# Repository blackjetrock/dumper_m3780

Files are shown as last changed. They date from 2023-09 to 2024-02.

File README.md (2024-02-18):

# dumper_m3780
Dumper for the M3780 microcontroller family
===========================================

Uses Sean Riddle's dumper circuit, but with a RP Pico instead of the
PIC. I ported Sean's code over to the Pico but couldn't get reliable
reads, so I rewrote it to use a generic system of injecting instructions
and used a more elaborate scheme to get the data out of the device. This 
is very much a hacked together tool specifically built to dump a ROM. It's not
a finished product.

The TEST pin handling is the same as Sean's code, but I have code that
can inject a (preset, in arrays) sequence of code into the device. This
allowed me to debug my instruction extraction and come up with a method of 
reading ROM bytes reliably. As I still had issues with a value every
few hundred bytes I now read each byte in the ROM many times and only if
that block read gives the same value is it used as the ROM byte value.
If the values aren't the same then the block of reads is re-done 
until it is. This means it takes a while to read the ROM but the 
values are, I think, correct. I checked operation with the Boris chess
computer ROM and I got a dump that matched Sean's ecxept for the last
few bytes which are, I think, unused values.

I then dumped the ROM from a device out of an HP82143 printer. The Boris 
and HP dumps are in this repository.

The PCB is powered by the Pico USB, whih also has a menu system to drive the
code and get dumps.

At the moment the code always dumps 4K

ERRATA
======

V1.0 PCB
--------

This version of the PCB does not work unless you add level shifters 
between the Pico and the 4066 control lines. I added a couple of FETs
onto my PCB manually. If you don't do this then the PCB will
not work.

Here's the V1.0 PCB I used:

IMAG4222

You can see a dc-dc converter module on the right, and the level shifters I wired in going from the 4066 
to the Pico on the left. The 40 pin IC is the M3780. the two LM317T circuits are on the right with their 
adjustment potentiometers.

Code
----
There's a menu system on the USB. Press 'h' to see the command list. To dump a ROM use 'u' then 'S' to dump the ROM. It takes a while as each byte
is read, when it's done the full dumpo is displayed. There's some problem that means that you need to select 'u'
before using 'S'. As this is a one or two use dumper, I'm not bothered by these wrinkles.

Links
=====

<pre>
Sean Riddle's site:                     https://seanriddle.com/
Forum thread:                           https://www.hpmuseum.org/forum/thread-20043.html
</pre>

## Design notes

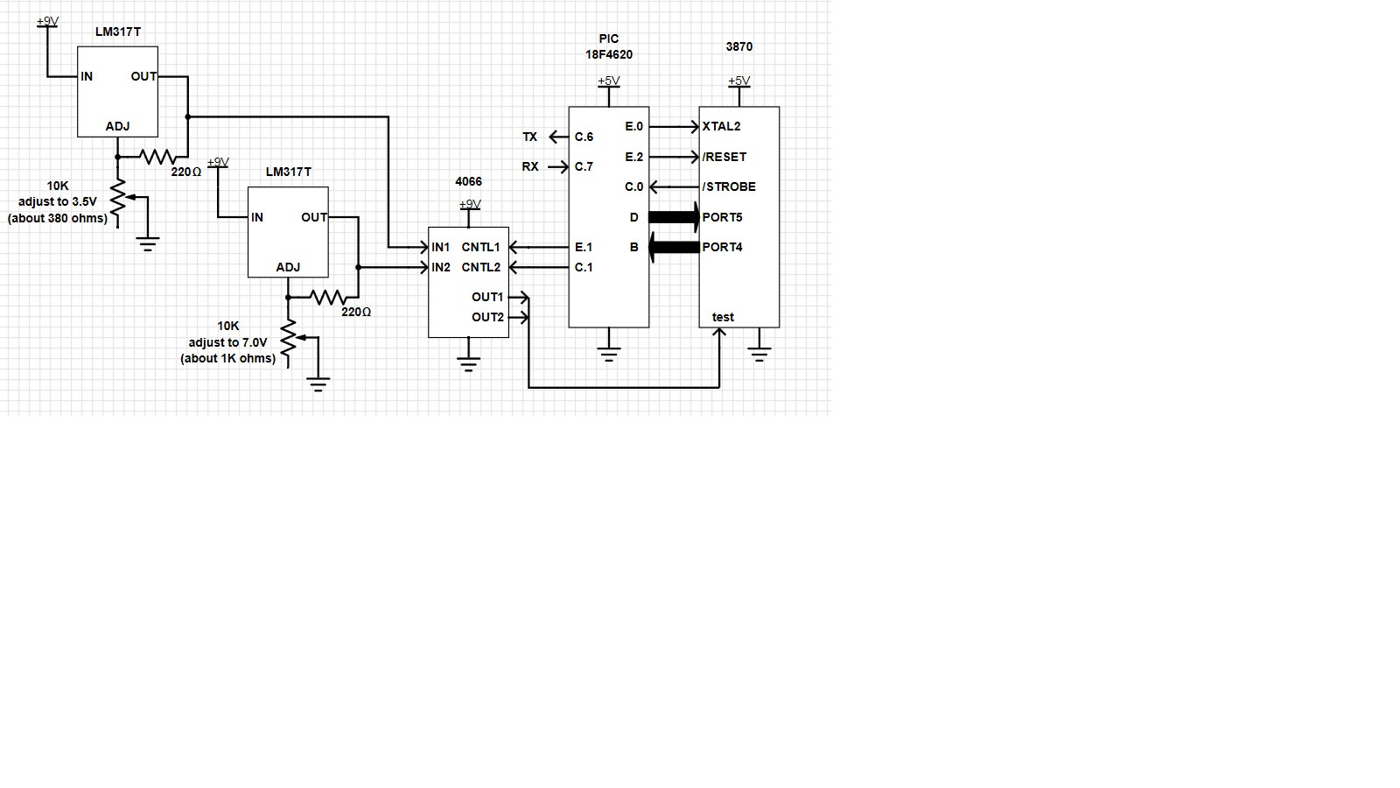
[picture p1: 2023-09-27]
sean_riddle/3870dumper.jpg

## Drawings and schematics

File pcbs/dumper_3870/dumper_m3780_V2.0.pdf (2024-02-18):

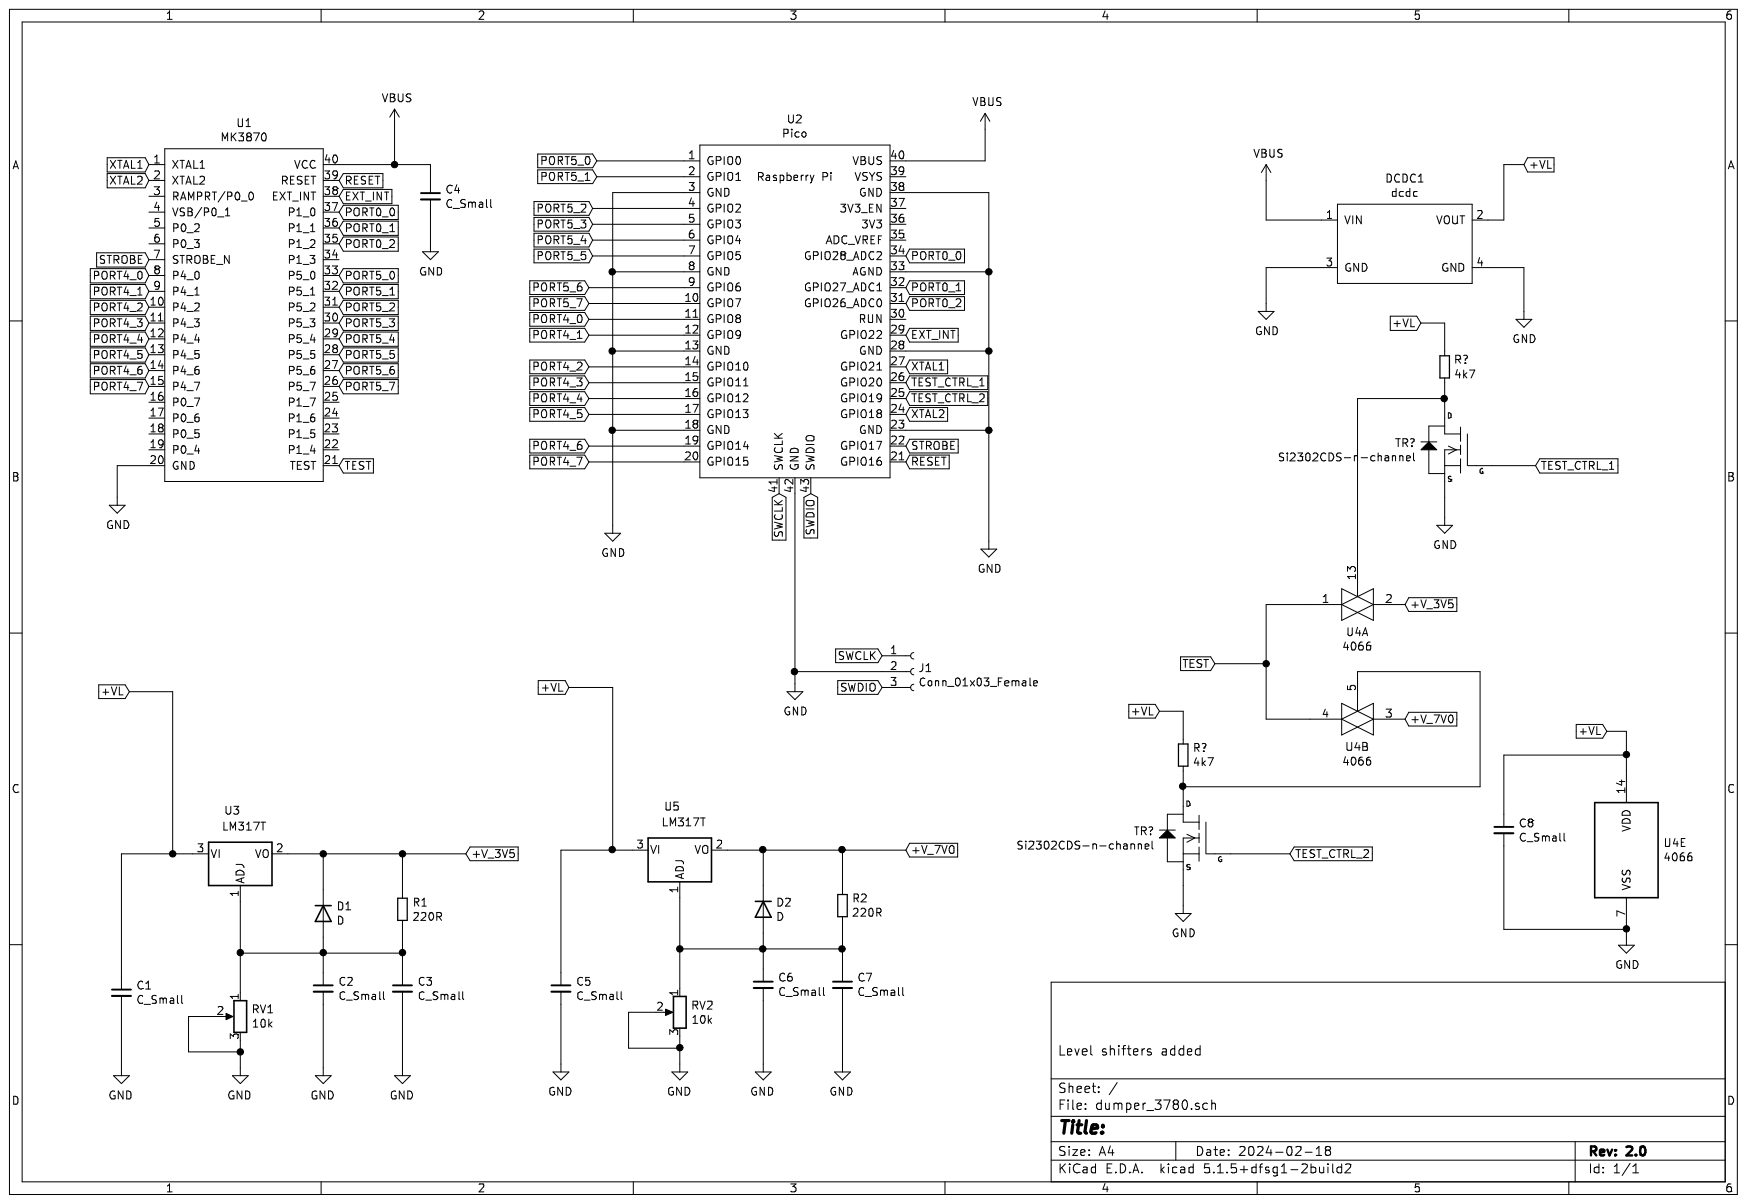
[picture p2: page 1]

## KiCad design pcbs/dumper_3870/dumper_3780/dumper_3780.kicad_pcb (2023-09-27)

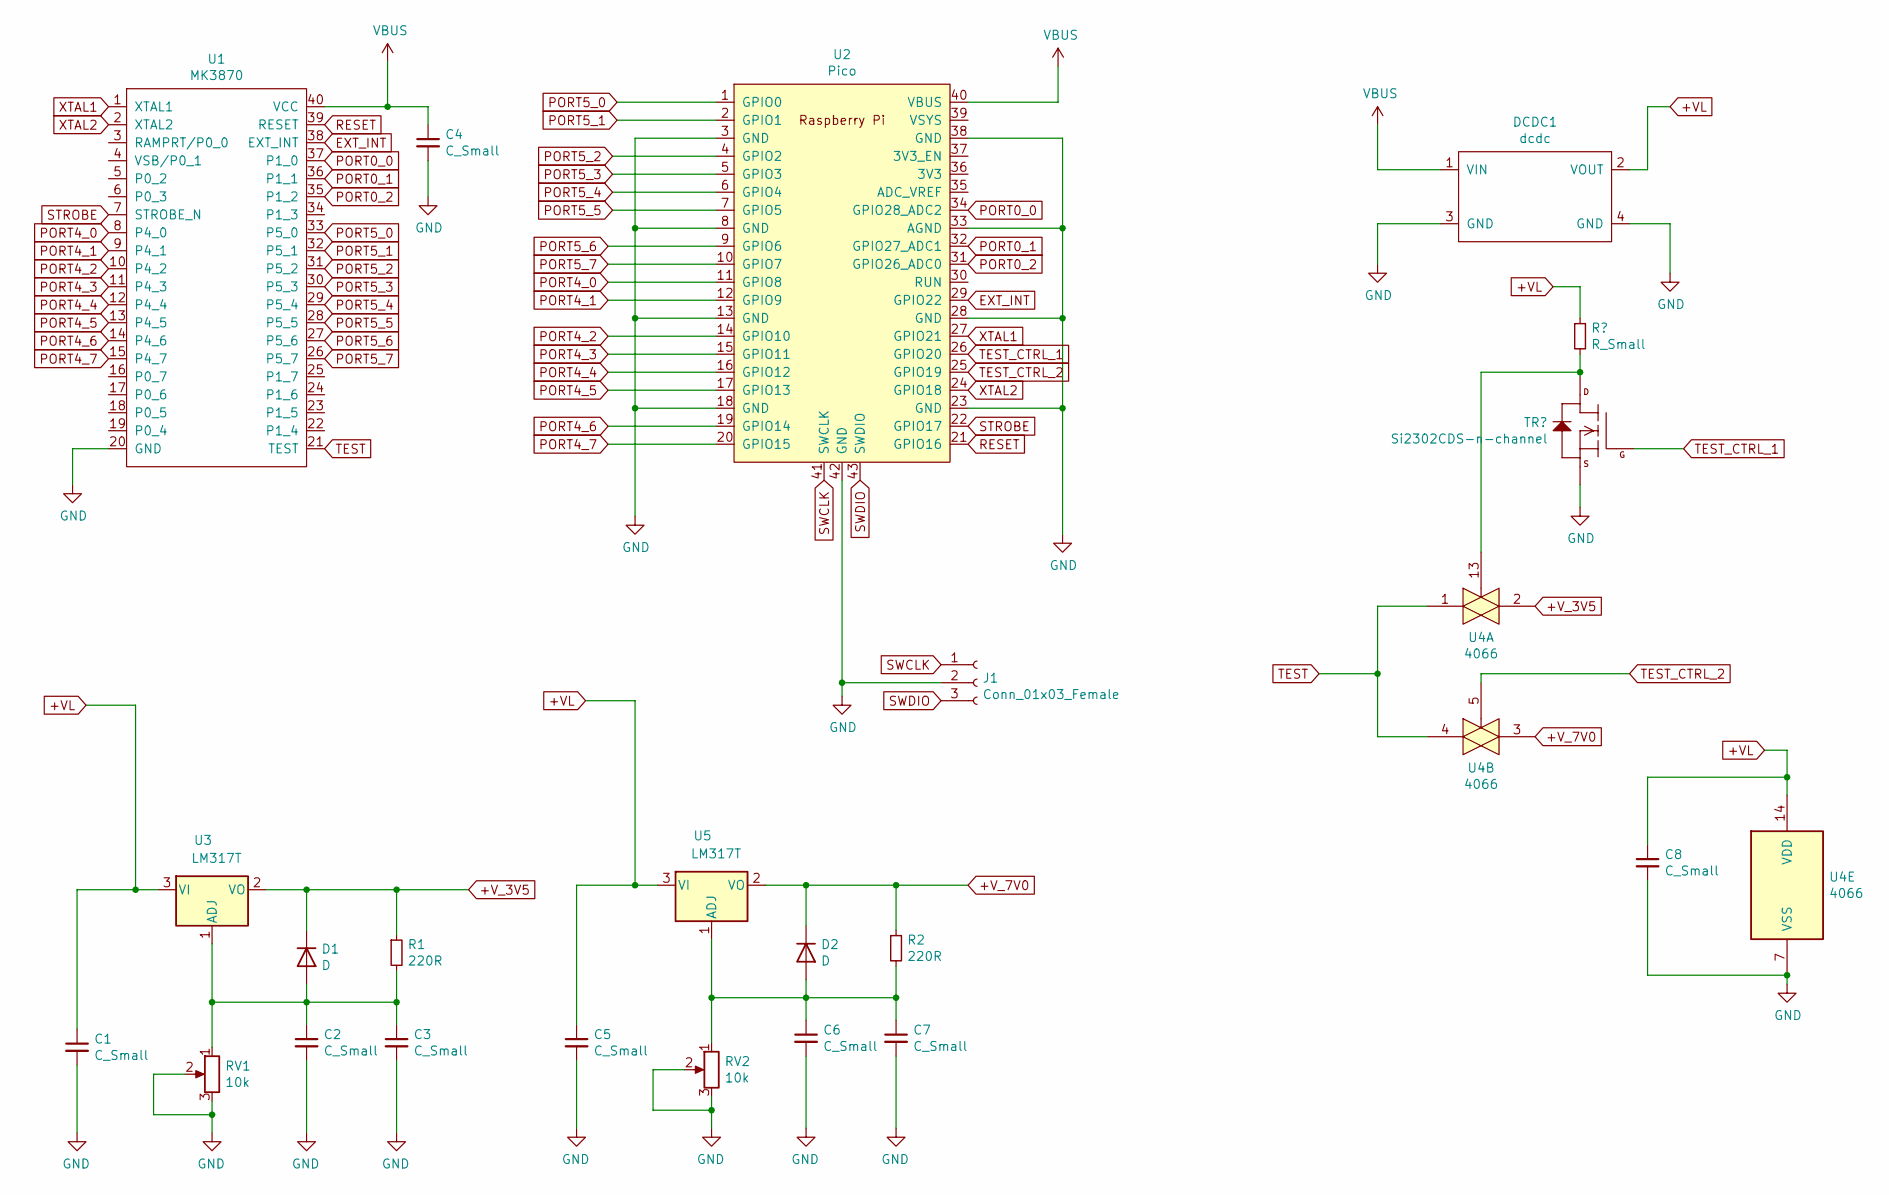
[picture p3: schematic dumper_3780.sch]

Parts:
C1, C2, C3, C4, C5, C6, C7, C8: C_Small; C_0805_2012Metric_Pad1.18x1.45mm_HandSolder
D1, D2: D; D_SOD-123
DCDC1: dcdc; PinSocket_1x04_P2.54mm_Vertical
J1: Conn_01x03_Female; PinSocket_1x03_P2.54mm_Vertical
R1, R2: 220R; R_0805_2012Metric_Pad1.20x1.40mm_HandSolder
RV1, RV2: 10k; Potentiometer_Bourns_3299W_Vertical
U1: MK3870; DIP-40_W15.24mm
U2: Pico; RPi_Pico_SMD_TH
U3, U5: LM317T; TO-220-3_Vertical
U4: 4066; SOIC-14_3.9x8.7mm_P1.27mm

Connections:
+VL: C1.1, C5.1, C8.1, DCDC1.2 (VOUT), U3.3 (VI), U4.14 (VDD), U5.3 (VI)
+V_3V5: D1.1 (K), R1.1, U3.2 (VO), U4.2
+V_7V0: D2.1 (K), R2.1, U4.3, U5.2 (VO)
EXT_INT: U1.38 (EXT_INT), U2.29 (GPIO22)
GND: C1.2, C2.2, C3.2, C4.2, C5.2, C6.2, C7.2, C8.2, DCDC1.3 (GND), DCDC1.4 (GND), J1.2, RV1.2, RV1.3, RV2.2, RV2.3, U1.20 (GND), U2.3 (GND), U2.8 (GND), U2.13 (GND), U2.18 (GND), U2.23 (GND), U2.28 (GND), U2.33 (AGND), U2.38 (GND), U2.42 (GND), U4.7 (VSS)
unnamed: C2.1, C3.1, D1.2 (A), R1.2, RV1.1, U3.1 (ADJ)
unnamed: C6.1, C7.1, D2.2 (A), R2.2, RV2.1, U5.1 (ADJ)
PORT0_0: U1.37 (P1_0), U2.34 (GPIO28_ADC2)
PORT0_1: U1.36 (P1_1), U2.32 (GPIO27_ADC1)
PORT0_2: U1.35 (P1_2), U2.31 (GPIO26_ADC0)
PORT4_0: U1.8 (P4_0), U2.11 (GPIO8)
PORT4_1: U1.9 (P4_1), U2.12 (GPIO9)
PORT4_2: U1.10 (P4_2), U2.14 (GPIO10)
PORT4_3: U1.11 (P4_3), U2.15 (GPIO11)
PORT4_4: U1.12 (P4_4), U2.16 (GPIO12)
PORT4_5: U1.13 (P4_5), U2.17 (GPIO13)
PORT4_6: U1.14 (P4_6), U2.19 (GPIO14)
PORT4_7: U1.15 (P4_7), U2.20 (GPIO15)
PORT5_0: U1.33 (P5_0), U2.1 (GPIO0)
PORT5_1: U1.32 (P5_1), U2.2 (GPIO1)
PORT5_2: U1.31 (P5_2), U2.4 (GPIO2)
PORT5_3: U1.30 (P5_3), U2.5 (GPIO3)
PORT5_4: U1.29 (P5_4), U2.6 (GPIO4)
PORT5_5: U1.28 (P5_5), U2.7 (GPIO5)
PORT5_6: U1.27 (P5_6), U2.9 (GPIO6)
PORT5_7: U1.26 (P5_7), U2.10 (GPIO7)
RESET: U1.39 (RESET), U2.21 (GPIO16)
STROBE: U1.7 (STROBE_N), U2.22 (GPIO17)
SWCLK: J1.1, U2.41 (SWCLK)
SWDIO: J1.3, U2.43 (SWDIO)
TEST: U1.21 (TEST), U4.1, U4.4
TEST_CTRL_1: U2.26 (GPIO20), U4.13
TEST_CTRL_2: U2.25 (GPIO19), U4.5
VBUS: C4.1, DCDC1.1 (VIN), U1.40 (VCC), U2.40 (VBUS)
XTAL1: U1.1 (XTAL1), U2.27 (GPIO21)
XTAL2: U1.2 (XTAL2), U2.24 (GPIO18)

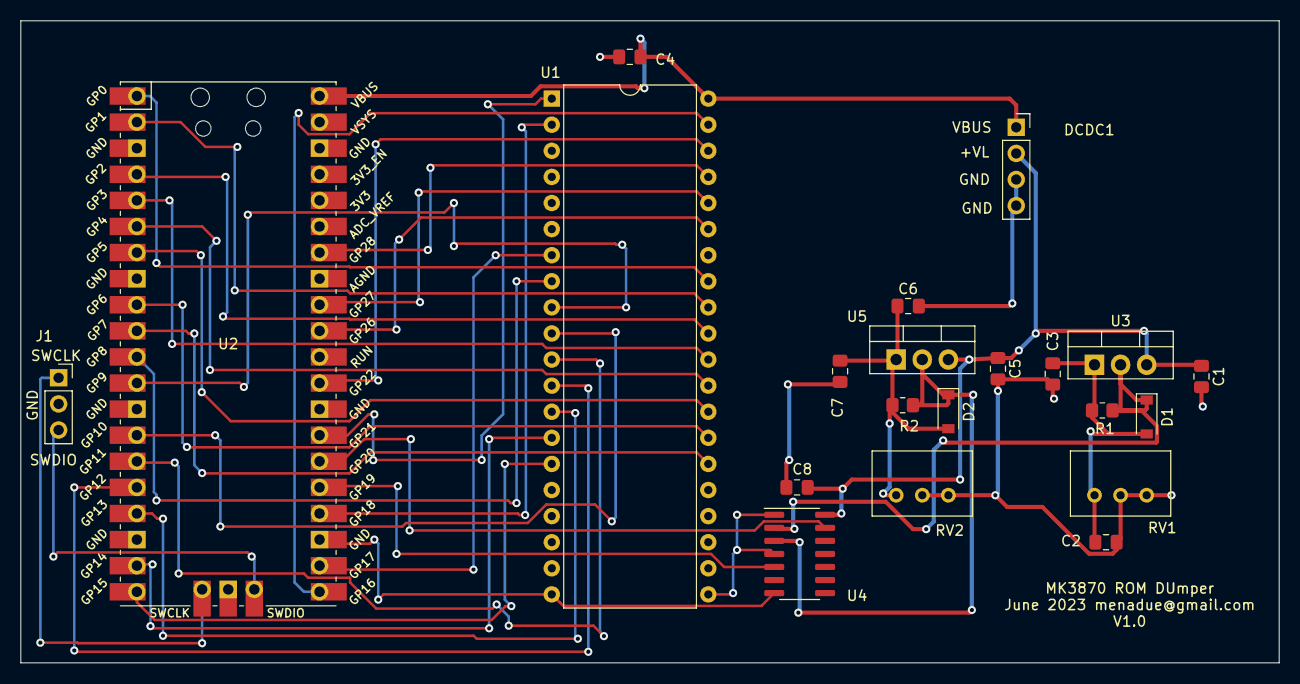
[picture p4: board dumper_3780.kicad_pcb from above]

Board: 2 copper layers, 122.5 x 62.5 mm, 21 parts (0 on the bottom side), 36 nets.

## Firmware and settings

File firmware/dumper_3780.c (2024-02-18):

////////////////////////////////////////////////////////////////////////////////
//
//  Dumper for M3780 Microcontrollers
//
////////////////////////////////////////////////////////////////////////////////
//
// Uses Sean Riddle's dumper circuit, but with a RP Pico instead of the
// PIC. I ported Sean's code over to the Pico but couldn't get reliable
// reads, so I rewrote it to use a generic system of injecting instructions
// and used a more elaborate scheme to get the data out of the device.
// 
//
////////////////////////////////////////////////////////////////////////////////

#include <ctype.h>
#include <math.h>
#include <stdio.h>
#include <stdlib.h>
#include <string.h>

#include "pico/stdlib.h"
#include "hardware/pio.h"
#include "hardware/dma.h"
#include "hardware/flash.h"
#include "hardware/structs/bus_ctrl.h"

#define DEBUG_STOP while(1) {}

// Some logic to analyse:
#include "hardware/structs/pwm.h"
#include "pico/multicore.h"
#include "pico/bootrom.h"

////////////////////////////////////////////////////////////////////////////////

#define DUMP_CODE      1
#define RAM_TEST_CODE  0

#if 0
// Gives about 2MHz clock
#define DUMP_ON_CLK   0
#define DELAY_CLK     2
#define DELAY_PORT    1
#define DELAY_VOLTS   1
#endif

int delay_clock_var = 2;

#if 1

#define DUMP_ON_CLK   0
#define DELAY_CLK     delay_clock_var
#define DELAY_PORT    1
#define DELAY_VOLTS   1
#endif

////////////////////////////////////////////////////////////////////////////////

#define CLOCK_DIV  30.0f

#define PORT_WIDTH 8

const int P_PORT5_0    = 0;
const int P_PORT5_1    = 1;
const int P_PORT5_2    = 2;
const int P_PORT5_3    = 3;
const int P_PORT5_4    = 4;
const int P_PORT5_5    = 5;
const int P_PORT5_6    = 6;
const int P_PORT5_7    = 7;

const int P_PORT4_0    = 8;
const int P_PORT4_1    = 9;
const int P_PORT4_2    = 10;
const int P_PORT4_3    = 11;
const int P_PORT4_4    = 12;
const int P_PORT4_5    = 13;
const int P_PORT4_6    = 14;
const int P_PORT4_7    = 15;

const int P_RESET      = 16;
const int P_STROBE     = 17;
const int P_XTAL2      = 18;

const int P_DRV_3V5    = 19;
const int P_DRV_7V0    = 20;
const int P_XTAL1      = 21;
const int P_EXT_INT    = 22;
const int P_PORT0_2    = 26;
const int P_PORT0_1    = 27;
const int P_PORT0_0    = 28;

typedef enum
  {
   TEST_PIN_FLOATING = 100,
   TEST_PIN_3V5,
   TEST_PIN_7V0,
  } TEST_PIN_VOLTAGE;
  

// Define some GPIO ports

const int port4[PORT_WIDTH] =
  {
   P_PORT4_0,
   P_PORT4_1,
   P_PORT4_2,
   P_PORT4_3,
   P_PORT4_4,
   P_PORT4_5,
   P_PORT4_6,
   P_PORT4_7,
  };

const int port5[PORT_WIDTH] =
  {
   P_PORT5_0,
   P_PORT5_1,
   P_PORT5_2,
   P_PORT5_3,
   P_PORT5_4,
   P_PORT5_5,
   P_PORT5_6,
   P_PORT5_7,
  };

// Opcodes (inverted)
#define DCI_OPCODE  (0x2A ^ 0xFF)
#define LM_OPCODE   (0x16 ^ 0xFF)
#define LR_OPCODE   (0x0E ^ 0xFF)
#define NOP_OPCODE  (0x2B ^ 0xFF)
#define ST_OPCODE   (0x17 ^ 0xFF)
#define LI_OPCODE   (0x20 ^ 0xFF)
#define INC_OPCODE  (0x1F ^ 0xFF)

////////////////////////////////////////////////////////////////////////////////
//
// Prototypes
//
////////////////////////////////////////////////////////////////////////////////

void serial_help(void);
void set_test_pin_voltage(TEST_PIN_VOLTAGE v);
int get_data_bus(void);
void detect_device(void);
void dump_rom(void);
void run_instructions(void);
int reset_and_detect(void);
void enable_rom(void);
void disable_rom(void);
void sweep_address(void);

volatile int perform_dump = 0;

////////////////////////////////////////////////////////////////////////////////
// Serial loop command structure
////////////////////////////////////////////////////////////////////////////////
  
typedef void (*FPTR)(void);

typedef struct
{
  char key;
  char *desc;
  FPTR fn;
} SERIAL_COMMAND;

int keypress = 0;
int parameter = 0;
int auto_increment_parameter = 0;
int auto_increment_address   = 0;

#define RAM_SIZE  (10*1024)

uint8_t ram_data[RAM_SIZE];
int dump_size = 0;

#define TEXT_PARAMETER_LEN 40

char text_parameter[TEXT_PARAMETER_LEN+1] = "";

int address = 0;

////////////////////////////////////////////////////////////////////////////////

////////////////////////////////////////////////////////////////////////////////

// Delay for less than a us
// This has to be tuned

void delay(int n)
{
  volatile int i;

  for(i=0; i<n; i++)
    {
    }
}

void set_gpio_input(int gpio_pin)
{
  gpio_init(gpio_pin);
  gpio_set_dir(gpio_pin, GPIO_IN);
  gpio_set_pulls(gpio_pin, 0, 0);

  printf("\nGPIO %d set as input", gpio_pin);
}

void set_gpio_output(int gpio_pin)
{
  gpio_init(gpio_pin);
  gpio_set_dir(gpio_pin, GPIO_OUT);
  gpio_put(gpio_pin, 0);
  printf("\nGPIO %d set as output", gpio_pin);
}

void set_port_input(const int port[PORT_WIDTH])
{
  for(int i=0; i<PORT_WIDTH; i++)
    {
      set_gpio_input(port[i]);
    }
}

void set_port_output(const int port[PORT_WIDTH])
{
  for(int i=0; i<PORT_WIDTH; i++)
    {
      set_gpio_output(port[i]);
    }
}

int read_port(const int port[PORT_WIDTH])
{
  int res = 0;

  delay(DELAY_PORT);
  
  for(int i=0; i<PORT_WIDTH; i++)
    {
      res |= (gpio_get(port[i]) << i);
    }

  return(res);
}

void write_port(const int port[PORT_WIDTH], int value)
{
  
  for(int i=0; i<PORT_WIDTH; i++)
    {
      if( value & (1<<i) )
	{
	  gpio_put(port[i], 1);
	}
      else
	{
	  gpio_put(port[i], 0);
	}
    }

  delay(DELAY_PORT);
}

void clock_low(void)
{
  gpio_put(P_XTAL2, 0);
  delay(DELAY_CLK);

#if DUMP_ON_CLK
  printf("\n   CLK LO DB:%02X", get_data_bus());
#endif
}



void clock_high(void)
{
  gpio_put(P_XTAL2, 1);

  delay(DELAY_CLK);

#if DUMP_ON_CLK
  printf("\n   CLK HI DB:%02X", get_data_bus());
#endif
}

void clock(void)
{
  clock_low();
  clock_high();
}

void double_clock(int n)
{
  for(int i=0; i<n; i++)
    {
      clock();
      clock();
    }
}


void set_data_bus(int value)
{
  write_port(port5, value);
}

int get_data_bus(void)
{
  return(read_port(port4));
}


void reset_low(void)
{
  gpio_put(P_RESET, 0);
}

void reset_high(void)
{
  gpio_put(P_RESET, 0);
}


void reset_device(void)
{
  printf("\nresetting device... ");
  reset_low();
  sleep_ms(300);
  reset_high();

  printf("  done.");
}


void display_ram_at(uint8_t *dat)
{
  int csum = 0;
  
  printf("\n");
  
  for(int z = 0; z<dump_size; z++)
    {
      int byte = 0;
      
      if( (z % 16) == 0)
	{
	  printf("\n%03X: ", z);
	}

      csum += *dat;
      
      printf("%02X ", *(dat++));
    }
  
  printf("\n");
  printf("\nCSUM:%08X\n", csum);

}

void display_ram(void)
{
  display_ram_at(&(ram_data[0]));
}


void cli_boot_mass(void)
{
  reset_usb_boot(0,0);
}

// Another digit pressed, update the parameter variable
void cli_digit(void)
{
  parameter *= 10;
  parameter += keypress-'0';
}

void cli_zero_parameter(void)
{
  parameter = 0;
}

void cli_set_address(void)
{
  address = parameter;
}

void cli_information(void)
{
  printf("\n");

  //  printf("\nNumber of reads  :%d", num_rd);
  //printf("\nNumber of writes :%d", num_wr);
  //  printf("\nNumber of loops: %d", loop_count);
  printf("\n");
}

void cli_text_param(void)
{
  int key;
  int done = 0;
  int i = 0;

  printf("\nType string and end with RETURN...\n");
  
  while( !done )
    {
      if( ((key = getchar_timeout_us(1000)) != PICO_ERROR_TIMEOUT))
	{
	  printf("%c", key);
	  
	  if( key == 13 )
	    {
	      done = 1;
	      continue;;
	    }

	  text_parameter[i++] = key;
	  
	  if( i >= (TEXT_PARAMETER_LEN-1) )
	    {
	      i--;
	    }
	}
    }
  
  text_parameter[i] = '\0';
}

void cli_set_test_3v5(void)
{
  set_test_pin_voltage(TEST_PIN_3V5);
}

void cli_set_test_7v0(void)
{
  set_test_pin_voltage(TEST_PIN_7V0);
}

void cli_set_test_float(void)
{
  set_test_pin_voltage(TEST_PIN_FLOATING);
}

////////////////////////////////////////////////////////////////////////////////

SERIAL_COMMAND serial_cmds[] =
  {
   {
    'h',
    "Serial command help",
    serial_help,
   },
   {
    '?',
    "Serial command help",
    serial_help,
   },
   {
    'I',
    "Information",
    cli_information,
   },
   {
    'u',
    "Dump ROM",
    dump_rom,
   },
   {
    'd',
    "Display RAM",
    display_ram,
   },
   {
    'D',
    "Detect device",
    detect_device,
   },
   {
    'A',
    "Set TEST pin to 3V5",
    cli_set_test_3v5,
   },
   {
    'B',
    "Set TEST pin to 7V0",
    cli_set_test_7v0,
   },
   {
    'F',
    "Set TEST pin to float",
    cli_set_test_float,
   },
   
   {
    'S',
    "Sweep address",
    sweep_address,
   },
   {
    'r',
    "Run instructions",
    run_instructions,
   },
   {
    'z',
    "Zero parameter",
    cli_zero_parameter,
   },
   {
    'A',
    "Set Address",
    cli_set_address,
   },
   {
    '0',
    "*Digit",
    cli_digit,
   },
   {
    '1',
    "*Digit",
    cli_digit,
   },
   {
    '2',
    "*Digit",
    cli_digit,
   },
   {
    '3',
    "*Digit",
    cli_digit,
   },
   {
    '4',
    "*Digit",
    cli_digit,
   },
   {
    '5',
    "*Digit",
    cli_digit,
   },
   {
    '6',
    "*Digit",
    cli_digit,
   },
   {
    '7',
    "*Digit",
    cli_digit,
   },
   {
    '8',
    "*Digit",
    cli_digit,
   },
   {
    '9',
    "*Digit",
    cli_digit,
   },
   {
    't',
    "Enter Text Parameter",
    cli_text_param,
   },
   {
    '!',
    "Boot to mass storage",
    cli_boot_mass,
   },
  };



void serial_help(void)
{
  printf("\n");
  
  for(int i=0; i<sizeof(serial_cmds)/sizeof(SERIAL_COMMAND);i++)
    {
      if( *(serial_cmds[i].desc) != '*' )
	{
	  printf("\n%c:   %s", serial_cmds[i].key, serial_cmds[i].desc);
	}
    }
  printf("\n0-9: Enter parameter digit");
}


void prompt(void)
{
  printf("\n\n(Text Parameter:'%s'", text_parameter);
  printf("\n(Parameter:%d (%04X) %c, Address:%d (%04X) %c) >",
	 parameter, parameter, auto_increment_parameter?'A':' ',
	 address,   address,   auto_increment_address?  'A':' ');
}


////////////////////////////////////////////////////////////////////////////////
//
// Serial CLI Handling
//
////////////////////////////////////////////////////////////////////////////////

int pcount = 0;
int periodic_read = 0;

void serial_loop()
{
  int  key;
  
  if( ((key = getchar_timeout_us(1000)) != PICO_ERROR_TIMEOUT))
    {
      for(int i=0; i<sizeof(serial_cmds)/sizeof(SERIAL_COMMAND);i++)
	{
	  if( serial_cmds[i].key == key )
	    {

	      keypress = key;
	      (*serial_cmds[i].fn)();
	      prompt();
	      break;
	    }
	}
    }
  else
    {
      // I have found that I need to send something if the serial USB times out
      // otherwise I get lockups on the serial communications.
      // So, if we get a timeout we send a spoace and backspace it. And
      // flush the stdio, but that didn't fix the problem but seems like a good idea.
      stdio_flush();
      printf(" \b");
    }
}

////////////////////////////////////////////////////////////////////////////////
//
// TEST pin drive. Only one voltage can be selected at a time
// as we don't want the two 317ts to have their outputs connected
// together
//
////////////////////////////////////////////////////////////////////////////////

void set_test_pin_voltage(TEST_PIN_VOLTAGE v)
{
  switch(v)
    {
    case TEST_PIN_FLOATING:
      gpio_put(P_DRV_7V0, 1);
      gpio_put(P_DRV_3V5, 1);
      delay(DELAY_VOLTS);
      break;
      
    case TEST_PIN_3V5:
      gpio_put(P_DRV_7V0, 1);
      gpio_put(P_DRV_3V5, 0);
      delay(DELAY_VOLTS);
      break;
      
    case TEST_PIN_7V0:
      gpio_put(P_DRV_3V5, 1);
      gpio_put(P_DRV_7V0, 0);
      delay(DELAY_VOLTS);
      break;
      
    default:
      printf("\nAttempted to drive an unsupported volatge to TEST pin\n");
      break;
    }
}

void detect_device(void)
{
  // Set reset low
  reset_low();

  // take test pin to 7V0 to disable ROM
  cli_set_test_7v0();

  //////////////////////////////AAAA//////////////////////////////////////////////
  //
  // Set a value on the data bus

  printf("\nSetting data bus to 0xA3...");
  set_data_bus(0xA3);

  int dbval = 0;
  
  if( (dbval = get_data_bus()) == 0x5C )
    {
      printf("\nDetected device. Data bus value = %02X", dbval );
    }
  else
    {
      printf("\nDid not detect device");
      printf("\n  Expected 0x5C on bus, read 0x%02X instead", dbval);
    }

  //////////////////////////////BBBB//////////////////////////////////////////////

  set_data_bus(0xFF);

  set_test_pin_voltage(TEST_PIN_3V5);

  reset_low();

}

int reset_and_detect(void)
{
  int result = 0;
  
  // Set reset low
  reset_low();

  // take test pin to 7V0 to disable ROM
  cli_set_test_7v0();

  // Set a value on the data bus

  //  printf("\nSetting data bus to 0xA3...");
  set_data_bus(0xA3);
  
  int dbval = 0;
  
  if( (dbval = get_data_bus()) == 0x5C )
    {
      // All OK
      result = 1;

      // printf("\nDetected device. Data bus value = %02X", dbval );
    }
  else
    {
      // Not detected
      //       printf("\nDid not detect device");
      //printf("\n  Expected 0x5C on bus, read 0x%02X instead", dbval);
    }

  set_data_bus(0xFF);
    
  // Clock while in reset
  //printf("\nClocking in reset...");
  double_clock(256);

  return(result);
}

////////////////////////////////////////////////////////////////////////////////

void release_reset(void)
{
  gpio_put(P_RESET, 1);
} 

////////////////////////////////////////////////////////////////////////////////
// Run instructions in the MK3780 by cloking it and waiting for strobe to go low
// This is an opcode load signal. We place the opcode on the bus and then clock
// the required number of cycles for that instruction, adding data if required (multi
// byte instructions). Strobe will then go low again and we load the next instruction

// Device is detected and reset at start of run

////////////////////////////////////////////////////////////////////////////////

#define MAX_INST_LEN 20

int inst_len_i = 0;
int inst_len[MAX_INST_LEN];
int first_strobe = 1;
int clock_cycle = 0;
int last_strobe = 1;
int run_inst_done = 0;
int ram_index= 0;
int stb_dat_i = 0;
volatile int grabbed_i = 0;
int got       = 0;

#define MAX_GRABBED   (1024)
volatile int grabbed[MAX_GRABBED];

int all_same = 1;
int first = -1;

#if DUMP_CODE
int stb_dat[] =
  {
   NOP_OPCODE, NOP_OPCODE, NOP_OPCODE, NOP_OPCODE, NOP_OPCODE, 
   DCI_OPCODE, 0xFF, 0xFF, 0xFF, 0xFF,
   DCI_OPCODE, 0xFF, 0xFF, (0x01 ^ 0xFF), 0xFF,
   LR_OPCODE,  0xFF, 0xFF,
   LM_OPCODE,  0xFF,
  };

#define ADDRL stb_dat[13]
#define ADDRH stb_dat[11]

int rom_enable[] =
  {
   0, 0, 0, 0, 0,
   0, 0, 0, 0, 0,
   0, 0, 0, 0, 0,
   0, 0, 0,
   0, 1
  };

int grab_data[] =
  {
   -1, -1, -1, -1, -1,
   -1, -1, -1, -1, -1,
   -1, -1, -1, -1, -1,
   -1, -1, -1,
   -1, 1
  };
#endif

#if RAM_TEST_CODE
int stb_dat[] =
  {
   NOP_OPCODE, NOP_OPCODE, NOP_OPCODE, NOP_OPCODE, NOP_OPCODE, 
   DCI_OPCODE, 0xFF, 0xFF, 0xFF, 0xFF,
   DCI_OPCODE, (0x07 ^ 0xFF), 0xFF, (0xFF ^ 0xFF), 0xFF,
   LM_OPCODE,  0xFF,
   INC_OPCODE, 
   DCI_OPCODE, (0x07 ^ 0xFF), 0xFF, (0xFF ^ 0xFF), 0xFF,
   ST_OPCODE,  0xFF,
   DCI_OPCODE, (0x07 ^ 0xFF), 0xFF, (0xFF ^ 0xFF), 0xFF,
   LM_OPCODE,  0xFF,
  };

#define ADDRL stb_dat[13]
#define ADDRH stb_dat[11]

int rom_enable[] =
  {
   0, 0, 0, 0, 0,
   0, 0, 0, 0, 0,
   0, 0, 0, 0, 0,
   0, 1,
   0,
   0, 0, 0, 0, 0,
   0, 0,
   0, 0, 0, 0, 0,
   0, 1,
  };

int grab_data[] =
  {
   -1, -1, -1, -1, -1,
   -1, -1, -1, -1, -1,
   -1, -1, -1, -1, -1,
   -1, 1,
   -1,
   -1, -1, -1, -1, -1,
   -1, -1,
   -1, -1, -1, -1, -1,
   -1, 1,

  };
#endif

#define STB_DAT_SIZE  (sizeof(stb_dat)/sizeof(int))
int next_stb_data(void)
{
  if( stb_dat_i >= STB_DAT_SIZE )
    {
      stb_dat_i = STB_DAT_SIZE-10;
    }

  // Enable rom if required
  if( rom_enable[stb_dat_i] )
    {
      enable_rom();
    }
  else
    {
      disable_rom();
    }
  
  //printf("\n    %02X", stb_dat[stb_dat_i]);          
  return(stb_dat[stb_dat_i++]);
}

void determine_cycle_count(int strobe)
{
  if( (strobe == 0) && (last_strobe == 1) )
    {
      // Disable ROM
      //  disable_rom();

      
      // Get data for STB read also enables/disables ROM
      set_data_bus(next_stb_data());

      if( inst_len_i < MAX_INST_LEN )
	{
	inst_len[inst_len_i++] = clock_cycle;
	}

      clock_cycle = 0;
      got = 0;
    }
  else
    {
      clock_cycle++;
    }

  last_strobe = strobe;
}

typedef struct _TRACE_S
{
  int cycle;
  int db;
  char *tag;
} TRACE_S;

#define NUM_TRACE 50000
//TRACE_S trace[NUM_TRACE];
int trace_i = 0;

void trace_this(int cyc, int databus, char *tag)
{
  if( trace_i < NUM_TRACE )
    {
#if 0
      trace[trace_i].cycle = cyc;
      trace[trace_i].db = databus;
      trace[trace_i].tag = tag;
#endif
      trace_i++;
    }
  else
    {
      run_inst_done = 1;
    }
}

////////////////////////////////////////////////////////////////////////////////
//
//
////////////////////////////////////////////////////////////////////////////////

#define MAX_SAME_DATA (4*1024)

int same_data[MAX_SAME_DATA];

void sweep_address(void)
{
  // Put address into the DCI instruction and run until we get all of the same value
  // back. Save that and move to next address

  for(int addr=0; addr<MAX_SAME_DATA; addr++)
    {
      ADDRH = (((addr & 0xFF00)>>8) ^ 0xFF);
      ADDRL = (((addr & 0x00FF)>>0)  ^ 0xFF);

      printf("\n");
      for(int j=0; j<20; j++)
	{

	  printf("%02X ", stb_dat[j]);
	}
      printf("\n");
      
      if( (addr % 16) == 0 )
	{
	  printf("\n%04X: ", addr);
	}

      int done = 0;
      
      while(!done)
	{
	  run_instructions();
	  if( all_same )
	    {
	      same_data[addr] = first;
	      done = 1;
	    }
	}
    }

  printf("\nFinal data:\n");
  
  for( int gg=0; gg<MAX_SAME_DATA; gg++)
    {
      if( (gg % 16) == 0 )
	{
	  printf("\n%04X: ", gg);
	}
      
      printf("%02X ", same_data[gg]);
    }

  printf("\n");

}

void run_instructions(void)
{
  inst_len_i    = 0;
  first_strobe  = 1;
  clock_cycle   = 0;
  last_strobe   = 1;
  run_inst_done = 0;
  ram_index     = 0;
  stb_dat_i     = 0;
  got           = 0;
  grabbed_i     = 0;
  trace_i       = 0;
  
  int databyte  = 0;
  
#if 0
  if( !reset_and_detect() )
    {
      printf("\n Device not detected\n");
      return;
    }
#else

  reset_low();

  disable_rom();
  set_data_bus(0xFF);
  
  double_clock(256);
  
#endif
  
  release_reset();
  
  while (!run_inst_done)
    {
      
      switch(clock_cycle)
	{
	case 3:
	  
	  // Enable the rom so it can be read
	  //enable_rom();
	  
	  // Remove the instruction code
	  set_data_bus(0xFF);
	  break;
	  
	case 3000:
	  // Something wrong
	  run_inst_done = 1;
	  break;
	}
      
      // Clock this cycle high
      clock_high();
      
      //printf("\n%3d: %02X  CLK H", clock_cycle, get_data_bus());
      trace_this(clock_cycle, databyte = get_data_bus(), "CLK H");

      // Strobe may have gone low, that would be an instruction fetch
      if( gpio_get(P_STROBE) == 0 )
	{
	  if( first_strobe )
	    {
	      first_strobe = 1;
	      determine_cycle_count(0);
	      
	      //printf("\n%3d: %02X  STB", clock_cycle, get_data_bus());
	      trace_this(clock_cycle, get_data_bus(), "STB");
	    }
	  else
	    {
	      //printf("\n%3d: %02X  STB", clock_cycle, get_data_bus());
	      trace_this(clock_cycle, get_data_bus(), "STB");
	      set_data_bus(0xFF);	      
	    }
	}
      else
	{
	  determine_cycle_count(1);
	}
      
      clock_low();
      
      //printf("\n%3d: %02X  CLK L", clock_cycle, get_data_bus());
      trace_this(clock_cycle, get_data_bus(), "CLK L");
      
      if( gpio_get(P_STROBE) == 0 )
	{
	  //determine_cycle_count(0);
	  //printf("\n%3d: %02X  STB", clock_cycle, get_data_bus());
	  trace_this(clock_cycle, databyte = get_data_bus(), "STB");

	  // grab the data if required
	  if( grab_data[stb_dat_i] != -1 )
	    {
	      if( !got && (grab_data[stb_dat_i] == clock_cycle) )
		{
		  // Grab another value
		  if( grabbed_i < MAX_GRABBED )
		    {
		      grabbed[grabbed_i++] = databyte;
		    }
		  got = 1;
		}
	    }
	  
	}
      else
	{
	  //determine_cycle_count(1);
	}
    }

#if 0
  printf("\n");
  
  for(int ii=0; ii<trace_i; ii++)
    {
      printf("\n%3d: %02X  %s", trace[ii].cycle, trace[ii].db, trace[ii].tag);
    }
  
  printf("\n\nCycle Lengths\n");
  
  for(int i=0; i<MAX_INST_LEN; i++)
    {
      printf("\n%3d: %d", i, inst_len[i]);
    }
  
  printf("\n");
#endif
  
  // Dump grabbed data

  printf("\nData\n");

  first = grabbed[0];
  all_same = 1;
  
  for( int gg=0; gg<grabbed_i; gg++)
    {
      if( grabbed[gg]!= first )
	{
	  all_same = 0;
	  printf("gg=%04X", gg);
	}
      
      if( (gg % 16) == 0 )
	{
	  printf("\n%04X: ", gg);
	}
      
      printf("%02X ", grabbed[gg]);
    }

  printf("\nAll same: %s", all_same?"YES":"NO");
  printf("\n");
  
}
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
int main()
{
  int gpio_states;

  stdio_init_all();
  sleep_ms(2000);
  
  // Make sure voltage drives are off

  printf("\nTurning TEST pin drive off...");

  set_gpio_output(P_DRV_3V5);
  set_gpio_output(P_DRV_7V0);

  gpio_put(P_DRV_3V5, 1);
  gpio_put(P_DRV_7V0, 1);

  printf("\n");
  printf("\n***********************");
  printf("\n* 3780 Dumper         *");
  printf("\n***********************");
  printf("\n");
  
  // Set up GPIOs

  printf("\nSetting GPIOs...");
  set_port_input(port4);
  set_port_output(port5);

  
  set_gpio_output(P_RESET);
  set_gpio_output(P_XTAL2);
  set_gpio_input(P_STROBE);

  reset_low();
  
  ////////////////////////////////////////////////////////////////////////////////
  //
  // Overclock as needed
  //
  ////////////////////////////////////////////////////////////////////////////////
  
  //#define OVERCLOCK 135000
  //#define OVERCLOCK 200000
#define OVERCLOCK 270000
  //#define OVERCLOCK 360000
  
#if OVERCLOCK > 270000
  /* Above this speed needs increased voltage */
  vreg_set_voltage(VREG_VOLTAGE_1_20);
  sleep_ms(1000);
#endif
  
  /* Overclock */
  set_sys_clock_khz( OVERCLOCK, 1 );

  multicore_launch_core1(core1_main);
    
  while(1)
    {
      serial_loop();
    }
}
